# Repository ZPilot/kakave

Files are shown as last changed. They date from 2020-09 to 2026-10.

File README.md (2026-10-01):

# kakave
<B>- Контроллер псевдо КМД+имитация 4х дисководов для УКНЦ (на SD карте)</B></Br>

<B>Идея:</B></Br>
Сделать простой для повторения и как можно более дешевый контроллер НГМД, который будет работать со встроенным в УКНЦ драйвером.

<B>Реализация:</B></Br>
Контроллер построен на базе платы Blackpill, имеющая на борту stm32f401 или stm32f411.

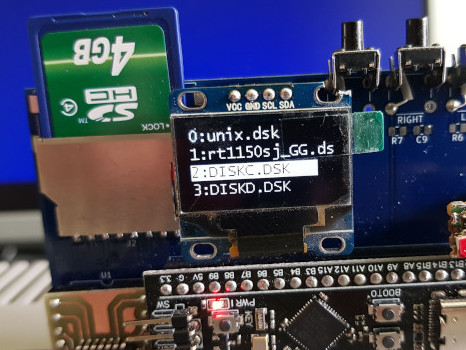
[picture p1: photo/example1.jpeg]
Kakave


<B>Что работает:</B></Br>
Чтение/запись с образов DSK размером 800 кБ, поддерживаются образы имеющие нестандартные размеры, но запись не гарантируется.
Работают: RT-11, Unix и другие ОС, программное обеспечение и игры из-под ОС.

<B>Что не работает:</B></Br>
Нет поддержки каталогов.</Br>
~~Игры от ИТО: ITO90.dsk - все игры с этого диска, ITO91.dsk - не работает PacMan.~~ (v1.1.0)

<B>Прошивка:</B></Br>
Готовые файлы записываются с адреса 0x08000000 (например, st-flash write f401test005.bin 0x08000000). Какой выбрать - по надписи на микроконтроллере Blackpill (или по chip id, который показывает st-info --probe):</Br>
- firmware401/Release/f401test005.bin - STM32F401CC (CCU6, chip id 0x423: 256 кБ flash, 64 кБ RAM). Работает и на STM32F401CE.</Br>
- firmware401/Release/f401cetest005.bin - STM32F401CE (CEU6, chip id 0x433: 512 кБ flash, 96 кБ RAM). Та же прошивка, собранная под CE: использует всю его память. На F401CC не работает.</Br>
- firmware/Release/f411test005.bin - STM32F411CE (CEU6, chip id 0x431). Для STM32F401 не подходит: работает на 100 МГц.</Br>
Все три работают с олед-дисплеями 128x64 (I2C, адрес 0x3C) на контроллерах SSD1306 (0.96"), SH1106 (1.3") и CH1116 (1.54"): тип контроллера определяется при включении по его байту состояния.</Br>
Сборка из командной строки: make (результат в build/), make release - собрать и положить в */Release/. Нужен arm-none-eabi-gcc в PATH или make TOOLCHAIN=&lt;каталог bin&gt;.</Br>
Файлы в */Release/ собраны GNU Arm Embedded 7-2018-q2-update (GCC 7.3.1, тот же компилятор, что в STM32CubeIDE 1.4): с ним make даёт точно такие же файлы. Более новые GCC (проверено 13.2) тоже собирают, но код получается другим.</Br>

<B>Ошибки:</B></Br>
На герберах перепутаны подписи под кнопками Left и Right. Кнопка Set расположена слишком близко к дисплею и мешает его установке.
В демонстрационном ролике старая модель корпуса с недостоверно подписанными светодиодными индикаторами. Индикаторы отображают сигнал "Мотор" и сигнал чтения/записи.

<B>Обратите внимание:</B></Br>
Платы BlackPill и олед-дисплея имеются в продаже с различающейся разводкой выводов.
При монтаже выводы разъема для программирования SCK и DIO запаиваются на плату.</Br>
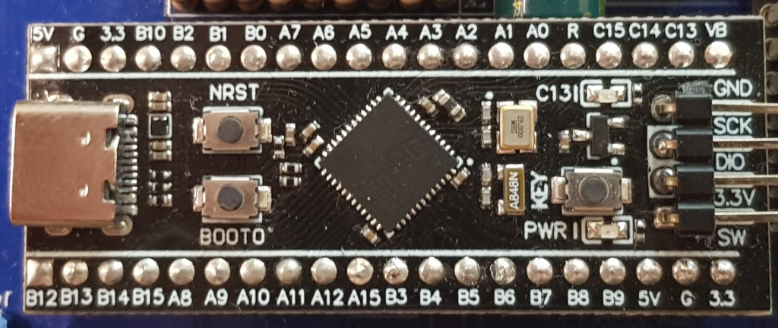
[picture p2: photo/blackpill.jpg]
blackpill

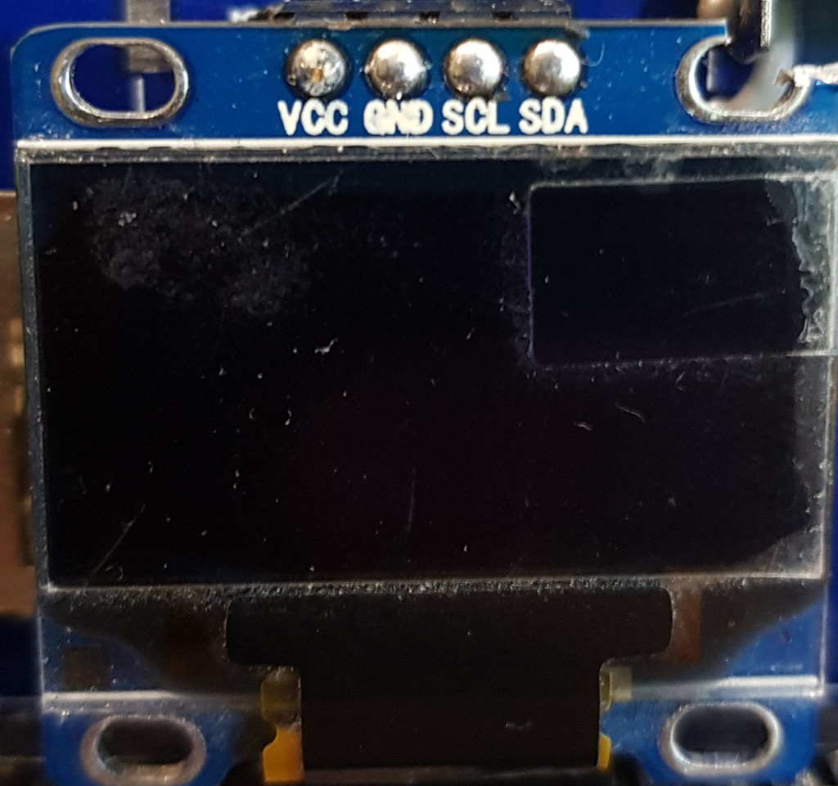
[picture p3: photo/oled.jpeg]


<B>Пример работы контроллера:</B></Br>
Example video (https://youtu.be/BQEt_0jdZwQ "Example video")
</Br>
<B>Сообществом были произведены следующие улучшения:</B></Br>
Новая трассировка платы и гербер-файлы: <a href="Community/">Community</a></Br>
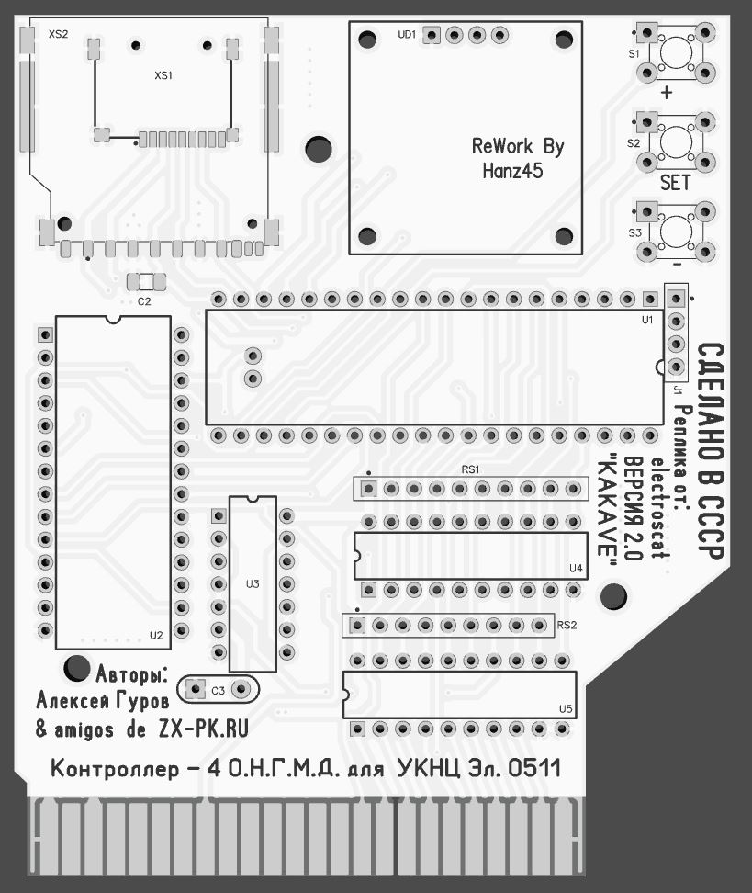
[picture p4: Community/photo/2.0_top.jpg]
внешний вид платы
</Br>
Стильный корпус со сменными передними накладками, там же несколько моделей в сборе</Br>
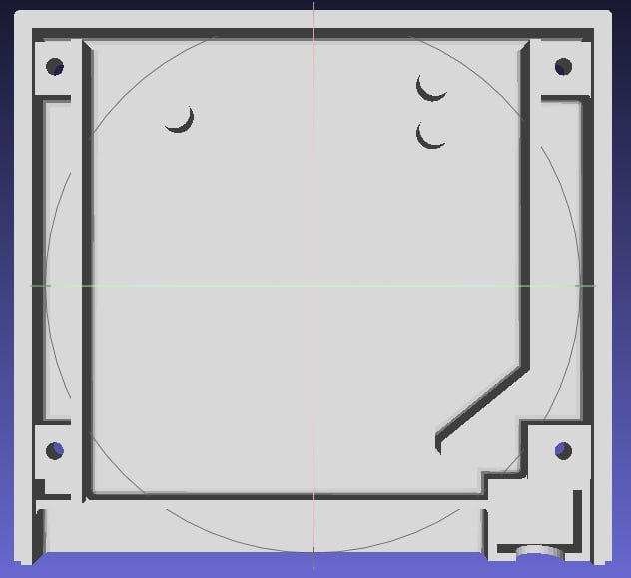
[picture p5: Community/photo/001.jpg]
</Br>
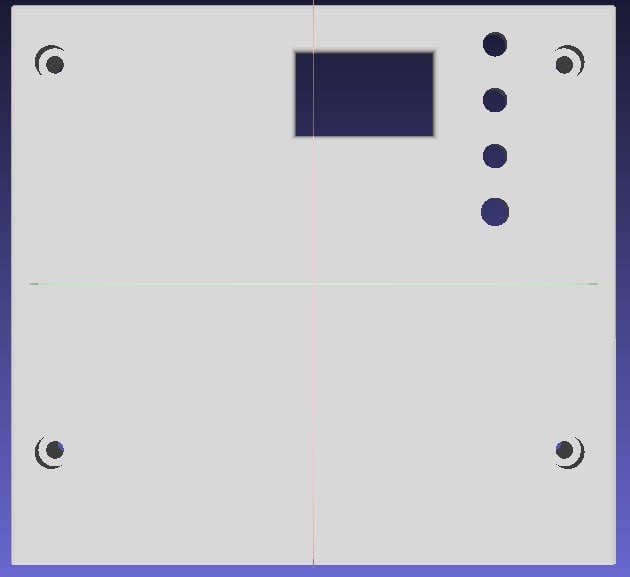
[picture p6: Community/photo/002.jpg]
</Br>
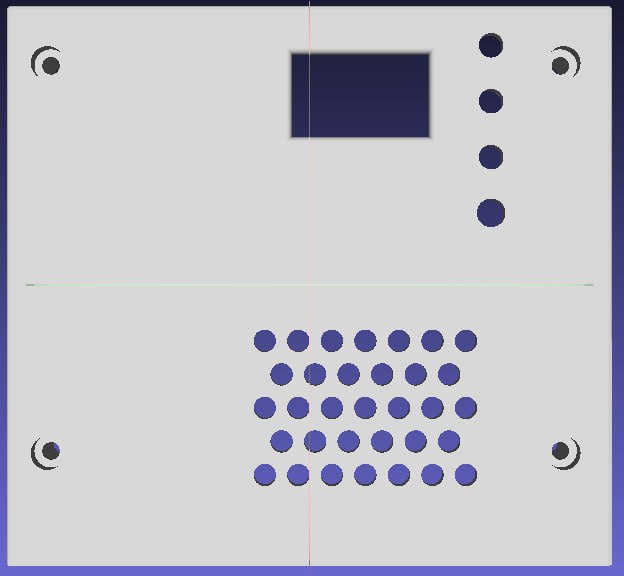
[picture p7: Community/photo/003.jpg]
</Br>
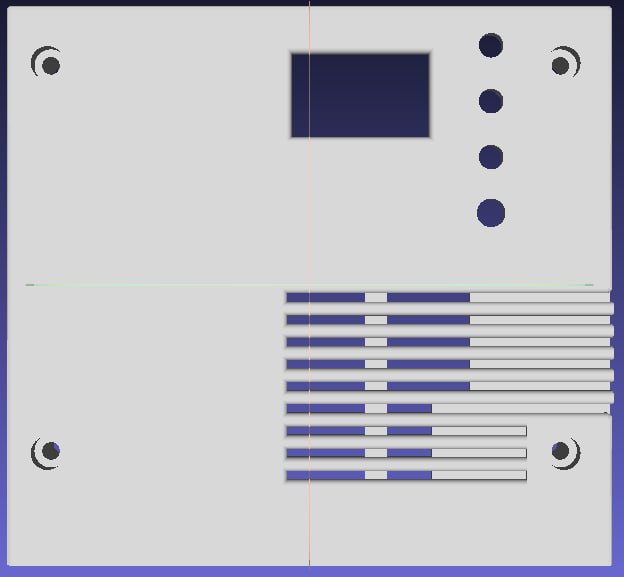
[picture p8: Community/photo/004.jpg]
</Br>
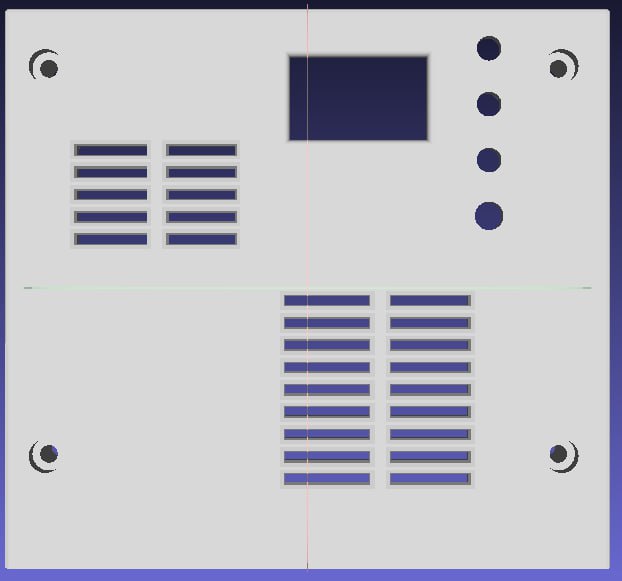
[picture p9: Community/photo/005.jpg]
</Br>
<B>Авторы модов:</B></Br>
@electroscatnes</Br>
Andrey Khristov</Br>
<B>Идейные вдохновители:<B></Br>
Alexey Kisly</Br>
@nzeemin</Br>
и все участники канала: <a href="https://t.me/MC0511UKNC">https://t.me/MC0511UKNC</a>

## CHANGELOG

v1.1.0 Правки
- исправлена ошибка загрузки игр с ITO дисков
- добавлена поддержка больших экранов на чипе CH1116
- добавлен CE build

v1.0.0 Исходная публичная версия

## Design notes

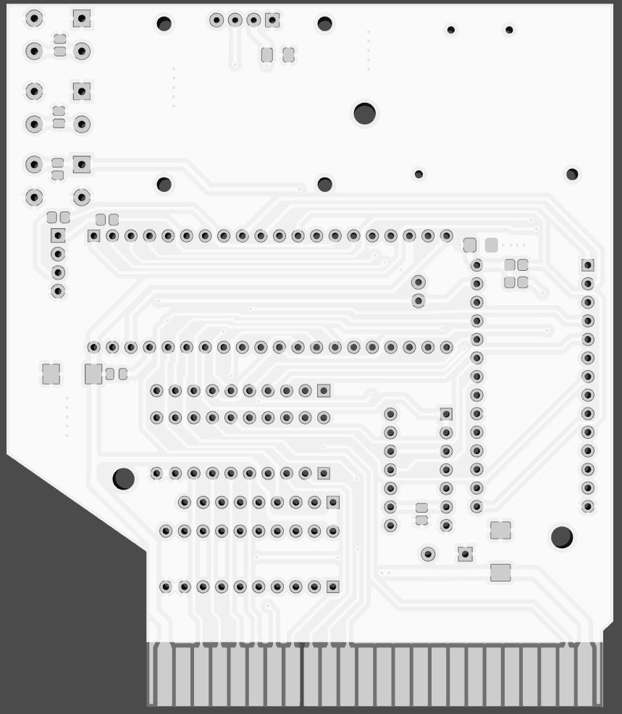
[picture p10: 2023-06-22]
Community/photo/2.1_bot.jpg

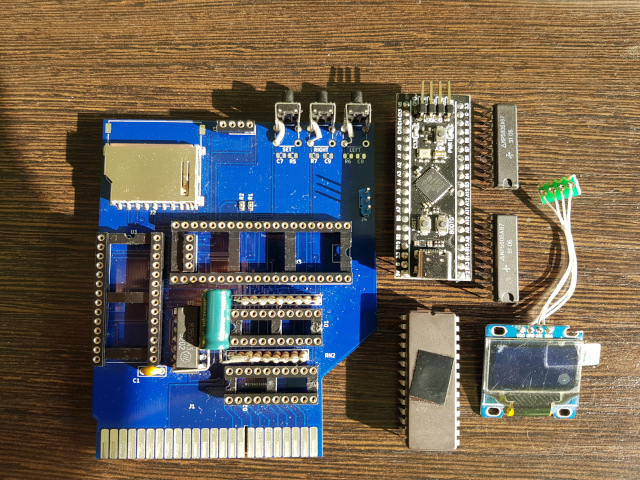
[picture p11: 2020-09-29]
photo/all.jpg

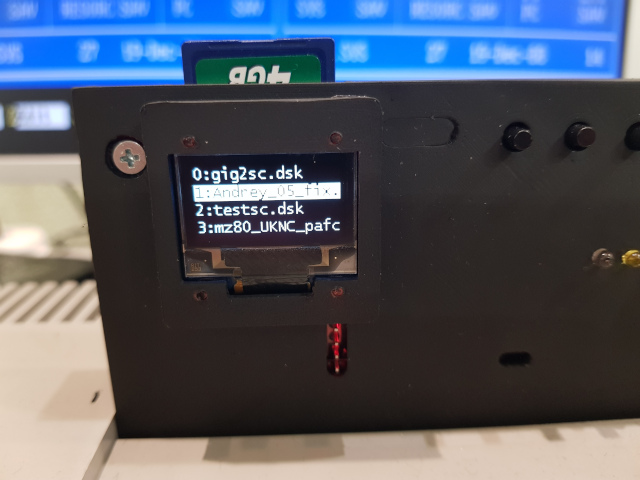
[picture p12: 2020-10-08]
photo/example2.jpg

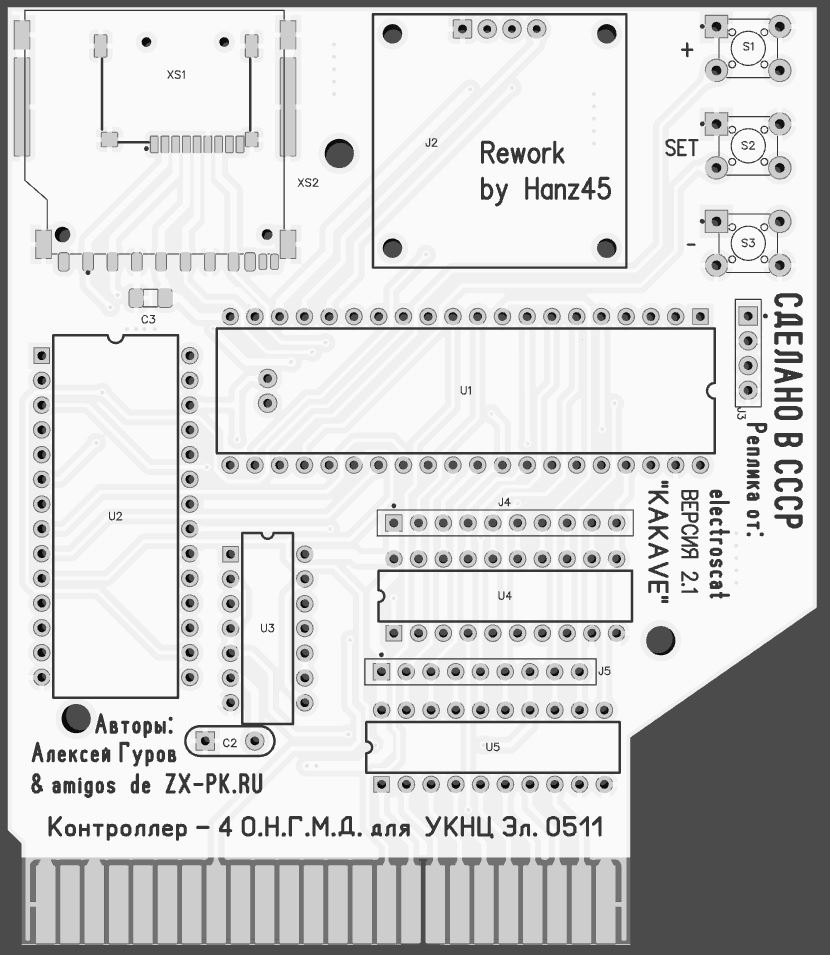
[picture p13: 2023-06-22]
Community/photo/2.1_top.jpg

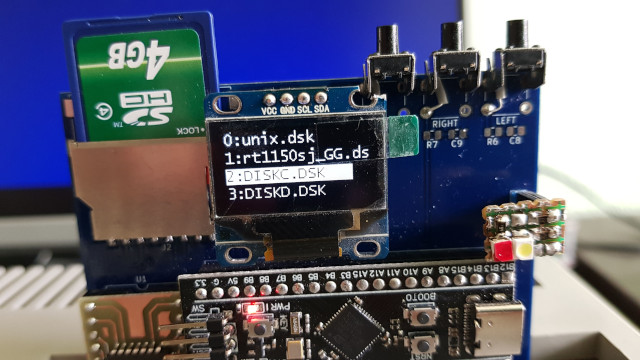
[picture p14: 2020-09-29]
photo/example.jpeg

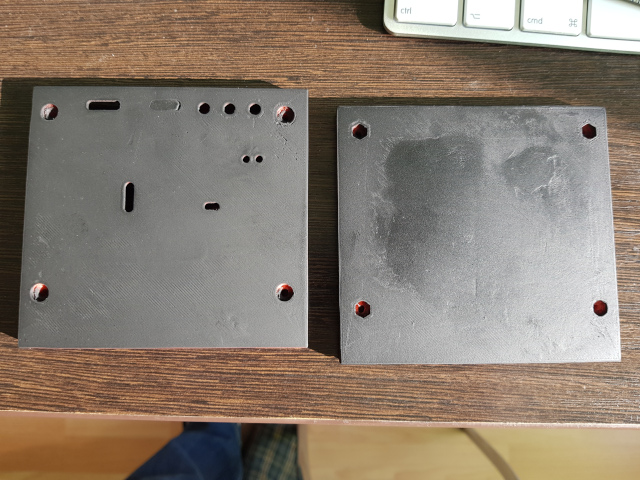
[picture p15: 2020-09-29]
photo/case.jpg

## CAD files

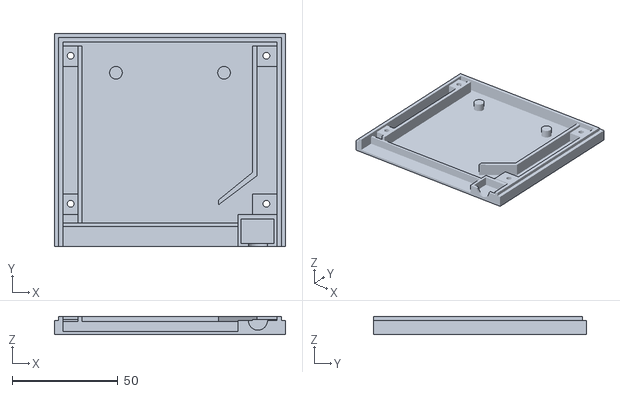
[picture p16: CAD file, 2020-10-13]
case/KKVE_N.stl
109.0 x 100.5 x 8.50

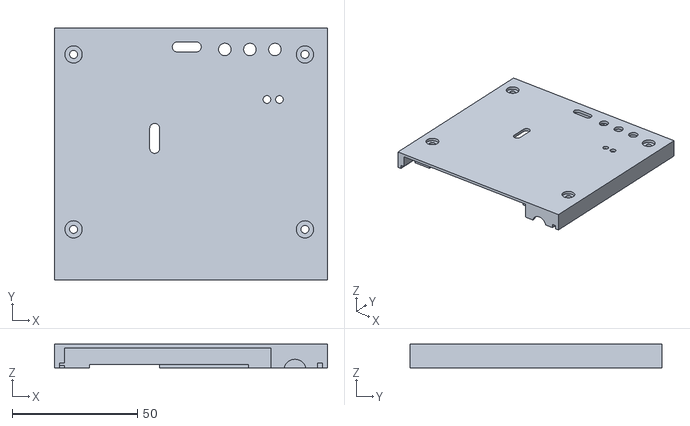
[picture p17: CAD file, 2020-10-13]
case/KKVE_V.stl
109.0 x 100.5 x 9.50

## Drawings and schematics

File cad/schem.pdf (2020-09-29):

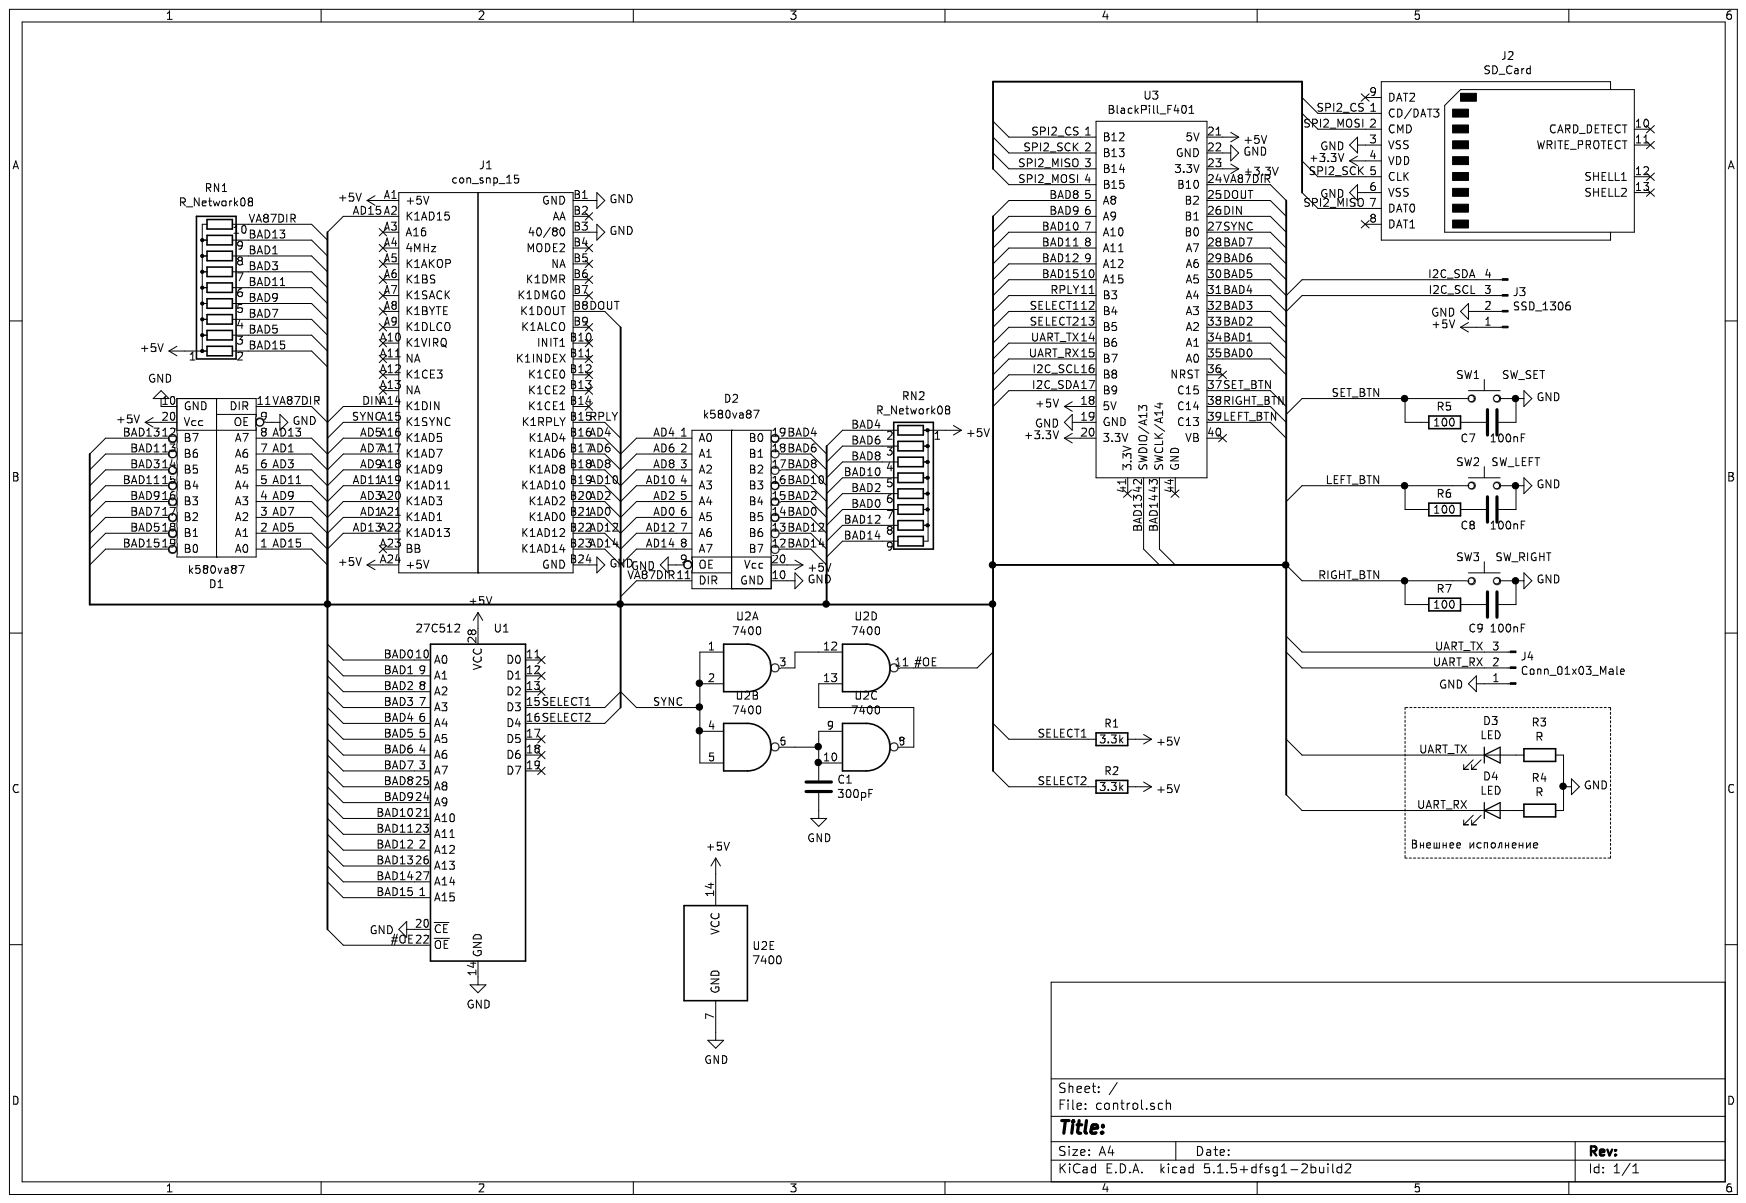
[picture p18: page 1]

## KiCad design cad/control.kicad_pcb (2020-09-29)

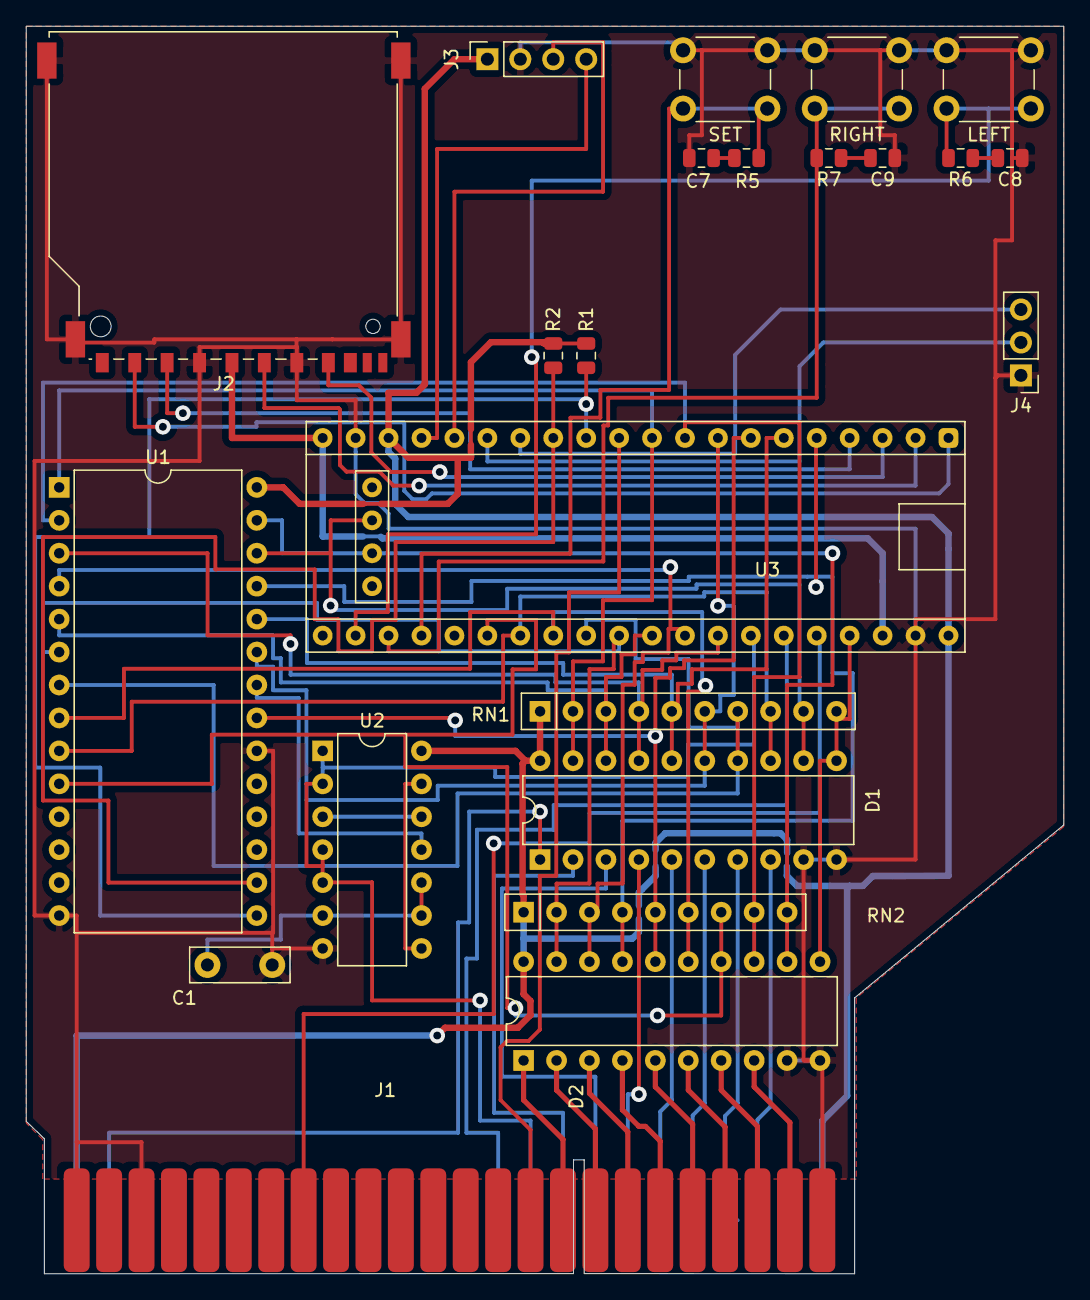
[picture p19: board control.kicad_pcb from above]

Board: 2 copper layers, 80.0 x 96.2 mm, 23 parts (0 on the bottom side), 60 nets.

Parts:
C1: 300pF; C_Disc_D7.5mm_W2.5mm_P5.00mm
C7, C8, C9: 100nF; C_0805_2012Metric
D1, D2: k580va87; DIP-20_W7.62mm
J1: con_snp_15; snp15
J2: SD_Card; SD_TE_2041021
J3: SSD_1306; PinSocket_1x04_P2.54mm_Vertical
J4: UART; PinHeader_1x03_P2.54mm_Vertical
LEFT: SW_LEFT; SW_PUSH_6mm_H7.3mm
R1, R2: 3.3k; R_0805_2012Metric
R5, R6, R7: 100; R_0805_2012Metric
RIGHT: SW_RIGHT; SW_PUSH_6mm_H7.3mm
RN1: R_Network08; R_Array_SIP10
RN2: R_Network08; R_Array_SIP9
SET: SW_SET; SW_PUSH_6mm_H7.3mm
U1: 27C512; DIP-28_W15.24mm
U2: 7400; DIP-14_W7.62mm
U3: BlackPill_F401

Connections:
+3V3: J2.4, U3.20, U3.23
+5V: D1.20, D2.20, J1.A1, J1.A24, J3.1, R1.1, R2.1, RN1.1, RN2.1, U1.28, U2.14, U3.18, U3.21
/#OE: U1.22, U2.11
/AD0: D2.6, J1.B21
/AD1: D1.7, J1.A21
/AD2: D2.5, J1.B20
/AD3: D1.6, J1.A20
/AD4: D2.1, J1.B16
/AD5: D1.2, J1.A16
/AD6: D2.2, J1.B17
/AD7: D1.3, J1.A17
/AD8: D2.3, J1.B18
/AD9: D1.4, J1.A18
/AD10: D2.4, J1.B19
/AD11: D1.5, J1.A19
/AD12: D2.7, J1.B22
/AD13: D1.8, J1.A22
/AD14: D2.8, J1.B23
/AD15: D1.1, J1.A2
/BAD0: D2.14, RN2.7, U1.10, U3.35
/BAD1: D1.13, RN1.8, U1.9, U3.34
/BAD2: D2.15, RN2.6, U1.8, U3.33
/BAD3: D1.14, RN1.7, U1.7, U3.32
/BAD4: D2.19, RN2.2, U1.6, U3.31
/BAD5: D1.18, RN1.3, U1.5, U3.30
/BAD6: D2.18, RN2.3, U1.4, U3.29
/BAD7: D1.17, RN1.4, U1.3, U3.28
/BAD8: D2.17, RN2.4, U1.25, U3.5
/BAD9: D1.16, RN1.5, U1.24, U3.6
/BAD10: D2.16, RN2.5, U1.21, U3.7
/BAD11: D1.15, RN1.6, U1.23, U3.8
/BAD12: D2.13, RN2.8, U1.2, U3.9
/BAD13: D1.12, RN1.9, U1.26, U3.42
/BAD14: D2.12, RN2.9, U1.27, U3.43
/BAD15: D1.19, RN1.2, U1.1, U3.10
/DIN: J1.A14, U3.26
/DOUT: J1.B8, U3.25
/I2C_SCL: J3.3, U3.16
/I2C_SDA: J3.4, U3.17
/LEFT_BTN: LEFT.1, R6.2, U3.39
/RIGHT_BTN: R7.2, RIGHT.1, U3.38
/RPLY: J1.B15, U3.11
/SELECT1: R1.2, U1.15, U3.12
/SELECT2: R2.2, U1.16, U3.13
/SET_BTN: R5.2, SET.1, U3.37
/SPI2_CS: J2.1, U3.1
/SPI2_MISO: J2.7, U3.3
/SPI2_MOSI: J2.2, U3.4
/SPI2_SCK: J2.5, U3.2
/SYNC: J1.A15, U2.1, U2.2, U2.4, U2.5, U3.27
/UART_RX: J4.2, U3.15
/UART_TX: J4.3, U3.14
/VA87DIR: D1.11, D2.11, RN1.10, U3.24
GND: C1.2, C7.1, C8.1, C9.1, D1.9, D1.10, D2.9, D2.10, J1.B1, J1.B3, J1.B24, J2.3, J2.6, J2.12, J3.2, J4.1, LEFT.2, RIGHT.2, SET.2, U1.14, U1.20, U2.7, U3.19, U3.22
unnamed: C1.1, U2.6, U2.9, U2.10
unnamed: C7.2, R5.1
unnamed: C8.2, R6.1
unnamed: C9.2, R7.1
unnamed: U2.3, U2.12
unnamed: U2.8, U2.13

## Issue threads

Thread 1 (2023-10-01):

No BOM and schematic for community board

nightgryphon, 2023-10-01:
The community baord have some changes after original project but there is no BOM for that community board nor the schematics so it is not possible to assemble community board correctly

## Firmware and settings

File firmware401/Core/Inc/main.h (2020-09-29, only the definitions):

#define LFL_BTN_Pin LL_GPIO_PIN_13
#define LFL_BTN_GPIO_Port GPIOC
#define RGT_BTN_Pin LL_GPIO_PIN_14
#define RGT_BTN_GPIO_Port GPIOC
#define SET_BTN_Pin LL_GPIO_PIN_15
#define SET_BTN_GPIO_Port GPIOC
#define SYNC_Pin LL_GPIO_PIN_0
#define SYNC_GPIO_Port GPIOB
#define DIN_Pin LL_GPIO_PIN_1
#define DIN_GPIO_Port GPIOB
#define DOUT_Pin LL_GPIO_PIN_2
#define DOUT_GPIO_Port GPIOB
#define VA87DIR_Pin LL_GPIO_PIN_10
#define VA87DIR_GPIO_Port GPIOB
#define SPI2_CS_Pin LL_GPIO_PIN_12
#define SPI2_CS_GPIO_Port GPIOB
#define RPLY_Pin LL_GPIO_PIN_3
#define RPLY_GPIO_Port GPIOB
#define SEL1_Pin LL_GPIO_PIN_4
#define SEL1_GPIO_Port GPIOB
#define SEL1_EXTI_IRQn EXTI4_IRQn
#define SEL2_Pin LL_GPIO_PIN_5
#define SEL2_GPIO_Port GPIOB
#define SEL2_EXTI_IRQn EXTI9_5_IRQn
#define LED1_Pin LL_GPIO_PIN_6
#define LED1_GPIO_Port GPIOB
#define LED2_Pin LL_GPIO_PIN_7
#define LED2_GPIO_Port GPIOB
#define NVIC_PRIORITYGROUP_0         ((uint32_t)0x00000007) /*!< 0 bit  for pre-emption priority,
#define NVIC_PRIORITYGROUP_1         ((uint32_t)0x00000006) /*!< 1 bit  for pre-emption priority,
#define NVIC_PRIORITYGROUP_2         ((uint32_t)0x00000005) /*!< 2 bits for pre-emption priority,
#define NVIC_PRIORITYGROUP_3         ((uint32_t)0x00000004) /*!< 3 bits for pre-emption priority,
#define NVIC_PRIORITYGROUP_4         ((uint32_t)0x00000003) /*!< 4 bits for pre-emption priority,

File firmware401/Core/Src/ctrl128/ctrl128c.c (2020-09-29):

/*
 * ctrl128c.c
 *
 *  Created on: Jul 31, 2020
 *      Author: alex
 */
#include "ctrl128.h"
#include "stdlib.h"
#include "../ff14/ff.h"
#include "../ff14/diskio.h"
#include "../ssd1306/ssd1306.h"


#define    DWT_CYCCNT    *(volatile unsigned long *)0xE0001004
#define    DWT_CONTROL   *(volatile unsigned long *)0xE0001000
#define    SCB_DEMCR     *(volatile unsigned long *)0xE000EDFC


volatile uint8_t VAR_AD[31];								//base memory array for system variables
//ctrl128
volatile uint16_t *RSN_RD	=(uint16_t*) (VAR_AD+0x00UL);	//Status
volatile uint16_t *RSN_WR	=(uint16_t*) (VAR_AD+0x02UL);	//CMD
volatile uint16_t *RDN_RD	=(uint16_t*) (VAR_AD+0x04UL);	//UKNC read
volatile uint16_t *RDN_WR	=(uint16_t*) (VAR_AD+0x06UL);	//UKNC write
volatile uint16_t *POS		=(uint16_t*) (VAR_AD+0x08UL);	//position in track
volatile uint8_t  *DRIVE	=(uint8_t*)  (VAR_AD+0x0AUL);	//Drive number
volatile uint8_t  *HEAD		=(uint8_t*)  (VAR_AD+0x0BUL);	//Side
volatile uint8_t  *TRACK	=(uint8_t*)  (VAR_AD+0x0CUL);	//Cylinder
volatile uint8_t  *SECTR	=(uint8_t*)  (VAR_AD+0x0DUL);	//Sector
volatile uint8_t  *MOTOR	=(uint8_t*)  (VAR_AD+0x0EUL);	//Motor on/off
volatile uint8_t  *GOR		=(uint8_t*)  (VAR_AD+0x0FUL);	//GOR
volatile uint8_t  *SELDRV	=(uint8_t*)	 (VAR_AD+0x10UL);	//Select/deselect dive
volatile uint8_t  *SAVE		=(uint8_t*)	 (VAR_AD+0x11UL);	//Save mode
volatile uint8_t  *READSD	=(uint8_t*)	 (VAR_AD+0x12UL);	//flag READFROMSD
volatile uint8_t  *UPDATE	=(uint8_t*)	 (VAR_AD+0x13UL);	//flag UPDATE
volatile uint8_t  *UPDATESD	=(uint8_t*)	 (VAR_AD+0x14UL);	//read/write sd
volatile uint16_t *GLPOS	=(uint16_t*) (VAR_AD+0x15UL);	//global pos in track
volatile uint8_t  *DSIZE	=(uint8_t*)	 (VAR_AD+0x16UL);	//drive size 4 byte!!DSIZE[4]

volatile uint16_t rawtrk[SECTORLEN/2];
extern const uint16_t rawtrk00[SECTORLEN/2];

volatile unsigned long count_tic=0;

FATFS drives;
FIL fl[4],fcfg;
FRESULT rc;
DIR dir;
//uint16_t nomfile=0;
static FILINFO fno;
uint8_t rdwrcfg=0;

const char cfgname[]={"kakave.cfg"};

struct _mfile mfile[4]={
	{"DISKA.DSK",0,0},
	{"DISKB.DSK",0,0},
	{"DISKC.DSK",0,0},
	{"DISKD.DSK",0,0}
};
UINT count=0;

volatile uint8_t str[50];
volatile uint8_t chksd=0;
uint32_t OCR;
uint8_t nomsel=0,set=0;

volatile static void updatesd(void);
static void printdsp(void);
static void printstr(uint8_t _nomsel);
static FRESULT getfilename(char *ffname,uint8_t drvsel,uint8_t direct);

FRESULT load_cfg(void)
{
	FRESULT res;
	f_lseek(&fcfg,0);
	res=f_read(&fcfg, (void *)mfile, sizeof(struct _mfile)*4, &count);
	if(count!=sizeof(struct _mfile)*4)res=FR_INVALID_OBJECT;
	return res;
}

FRESULT save_cfg(void)
{
	FRESULT res;
	f_lseek(&fcfg,0);
	res=f_write(&fcfg, (void *)mfile, sizeof(struct _mfile)*4, &count);
	f_sync(&fcfg);
	return res;
}

void mountdsk(void)
{
	GPIOB->BSRR=SPI2_CS_Pin;

	fast_memcpy2((void*)rawtrk,(void*)rawtrk00,SECTORLEN);

	fast_memset((void *)fl,0,sizeof(fl));
	fast_memset((void *)&dir,0,sizeof(dir));

	while(f_mount(&drives,"",1)!=FR_OK)
	{
		GPIOB->BSRR|=LED1_Pin;
		LL_mDelay(50);
		GPIOB->BSRR|=LED1_Pin<<16;
		LL_mDelay(50);
	}

	rc=f_open(&fcfg, cfgname, FA_OPEN_ALWAYS|FA_READ|FA_WRITE);
	if(rc==FR_OK)
	{
		if(!rdwrcfg)
		{
			if(load_cfg()!=FR_OK)save_cfg();
		}
		else rdwrcfg=0,save_cfg();
	}

	f_opendir(&dir, "/");

	rc=f_open(&fl[0], mfile[0].fname, FA_READ|FA_WRITE);
	if(rc==FR_OK)
	{
		mfile[0].mnt=1;
		DSIZE[0]=f_size(&fl[0])==409600?39:79;
		GPIOB->BSRR|=LED1_Pin;
		LL_mDelay(50);
		GPIOB->BSRR|=LED1_Pin<<16;
		LL_mDelay(50);
	}
	else mfile[0].mnt=0;
	rc=f_open(&fl[1], mfile[1].fname, FA_READ|FA_WRITE);
	if(rc==FR_OK)
	{
		mfile[1].mnt=1;
		DSIZE[1]=f_size(&fl[1])==409600?39:79;
		GPIOB->BSRR|=LED1_Pin;
		LL_mDelay(50);
		GPIOB->BSRR|=LED1_Pin<<16;
		LL_mDelay(50);
	}
	else mfile[1].mnt=0;

	rc=f_open(&fl[2], mfile[2].fname, FA_READ|FA_WRITE);
	if(rc==FR_OK)
	{
		mfile[2].mnt=1;
		DSIZE[2]=f_size(&fl[2])==409600?39:79;
		GPIOB->BSRR|=LED1_Pin;
		LL_mDelay(50);
		GPIOB->BSRR|=LED1_Pin<<16;
		LL_mDelay(50);
	}
	else mfile[2].mnt=0;

	rc=f_open(&fl[3], mfile[3].fname, FA_READ|FA_WRITE);
	if(rc==FR_OK)
	{
		mfile[3].mnt=1;
		DSIZE[3]=f_size(&fl[3])==409600?39:79;
		GPIOB->BSRR|=LED1_Pin;
		LL_mDelay(50);
		GPIOB->BSRR|=LED1_Pin<<16;
		LL_mDelay(50);
	}
	else mfile[3].mnt=0;
}

void ctrl128ini(void)
{
	*RSN_RD		=0x00;	//Status
	*RSN_WR		=0x00;	//CMD
	*RDN_RD		=0x00;	//UKNC read
	*RDN_WR		=0x00;	//UKNC write
	*POS		=0x00;	//position in track
	*DRIVE		=0x00;	//Drive number
	*HEAD		=0x00;	//Side
	*TRACK		=0x02;	//Cylinder
	*SECTR		=0x01;	//Sector
	*MOTOR		=0x00;	//Motor on/off
	*GOR		=0x00;	//GOR
	*SELDRV		=0x00;	//Select/deselect dive
	*SAVE		=0x00;
	*READSD		=0x00;	//flag READFROMSD
	*UPDATE		=0x00;	//flag UPDATE
	*UPDATESD	=0x00;	//read/write sd
	*GLPOS		=0x00;	//global pos in track
	DSIZE[0]=DSIZE[1]=DSIZE[2]=DSIZE[3]=79; //drivesize = 39/79

	SSD1306_Init();

	mountdsk();

	printdsp();
	//TIM3 - timer for data out
	LL_TIM_SetCounter(TIM3, 0);
	LL_TIM_ClearFlag_UPDATE(TIM3);
	LL_TIM_EnableIT_UPDATE(TIM3);
	LL_TIM_EnableCounter(TIM3);
	//TIM4 - timer for test SD insert
	LL_TIM_ClearFlag_UPDATE(TIM4);
	LL_TIM_EnableIT_UPDATE(TIM4);
	//LL_TIM_EnableCounter(TIM4);
	//TIM10 - timer 3 milS head next rtack
	LL_TIM_ClearFlag_UPDATE(TIM10);
	LL_TIM_EnableIT_UPDATE(TIM10);
}

volatile void ctrl128loop(void)
{
	uint8_t displaymod=0;
	ctrl128ini();


	/*SCB_DEMCR |= CoreDebug_DEMCR_TRCENA_Msk;// разрешаем использовать DWT
	DWT_CYCCNT = 0;// обнуляем значение
	DWT_CONTROL|= DWT_CTRL_CYCCNTENA_Msk; // включаем счётчик
	//count_tic = DWT_CYCCNT;//смотрим сколько натикало
	asm("nop");*/

	while(1)
	{
		if(*UPDATESD)*UPDATESD=0,updatesd();
		if(*MOTOR&*SELDRV)
		{
			if(TIM4->CR1&TIM_CR1_CEN)
			{
				LL_TIM_DisableCounter(TIM4);
				GPIOB->BSRR=LED1_Pin;
				displaymod=0;
				*UPDATE=0;
				fast_fill(0);
			}
		}
		else
		{
			if(!TIM4->CR1&TIM_CR1_CEN)
			{
				GPIOB->BSRR=LED1_Pin<<16;
				LL_TIM_EnableCounter(TIM4);
				displaymod=1;
				chksd=0;
			}
		}
		if(*UPDATE)
		{
			*UPDATE=0;
			if(!chksd)printdsp();
			if(chksd%10==0)
			{
				if(disk_ioctl(0,MMC_GET_OCR,&OCR)!=RES_OK)
				{
					mfile[0].nomfile=0;mfile[1].nomfile=0;
					mfile[2].nomfile=0;mfile[3].nomfile=0;
					rdwrcfg=0;
					mountdsk();
				}
			}
			if(chksd==100)fast_fill(0);
			chksd+=chksd<100?1:0;
		}
		if(displaymod)
		{
			switch((GPIOC->IDR&(LFL_BTN_Pin|RGT_BTN_Pin|SET_BTN_Pin))^0xE000)
			{
			case SET_BTN_Pin:
				if(chksd>1)set=!set,printstr(nomsel);
				if(!set)rdwrcfg=1,mountdsk();
				chksd=0;
				break;
			case RGT_BTN_Pin:
				if(nomsel && chksd>1 &&!set)--nomsel,printstr(nomsel);
				else if(set && chksd>1)getfilename(mfile[nomsel].fname,nomsel,0),printstr(nomsel);
				chksd=0;
				break;
			case LFL_BTN_Pin:
				if(nomsel<3  && chksd>1 &&!set)++nomsel,printstr(nomsel);
				else if(set && chksd>1)getfilename(mfile[nomsel].fname,nomsel,1),printstr(nomsel);
				chksd=0;
				break;
			default:
				break;
			}
		}
	}
}
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

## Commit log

2020-09-29 for stm32f411
2020-09-29 for stm32f401
2020-09-29 KiCAD files
    [control-B_Cu.gbl, control-B_Mask.gbs, control-B_Paste.gbp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]
2020-09-29 Delete ctrl128a (копия).s_
    Modify
2020-10-02 case stl files
    [UKNC_bottom.stl, UKNC_top.stl]
2023-04-03 Author Denis Nikolaevich
    [kakave-master_project_mod_II.drl, kakave-master_project_mod_II_Ф1_верх.GTL, kakave-master_project_mod_II_Ф2_низ.GBL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]
2023-06-22 the latest version of the board and case
    [END_CASE__N.stl, END_CASE__V.stl, END_CASE__V_CONV.stl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]
2026-10-01 CH1116 interrupt refresh

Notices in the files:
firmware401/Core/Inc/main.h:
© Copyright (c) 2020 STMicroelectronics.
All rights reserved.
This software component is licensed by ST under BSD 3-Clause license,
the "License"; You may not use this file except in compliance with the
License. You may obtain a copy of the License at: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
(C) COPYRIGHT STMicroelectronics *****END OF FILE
